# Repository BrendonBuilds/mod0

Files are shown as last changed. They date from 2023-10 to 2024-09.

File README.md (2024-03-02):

# mod0

### mod0 is an undefined, modular machine platform

- *This project is a work in progress*
- *Modules will be added as they are physically validated*
- *Expect files to change*

## Platform goals

- Extremely simple assembly that will result in precise control with minimal calibration
- Support for any combination of steppers (NEMA14/17), electronics (RRF/Klipper) and extruders
- Subcomponents can be assembled and calibrated independently
- Subcomponents can be separated for travel and quickly reassembled
- Packs flat for travel while staying mostly assembled
- Open Source

Feeling appreciative? Pay it forward! Consider supporting one of these charities!

[Sanjay Mortimer Foundation](https://www.sanjaymortimerfoundation.org/)

[Sanjay Mortimer Foundation PayPal](https://www.paypal.com/donate/?hosted_button_id=VUB6NVF83EH5J)

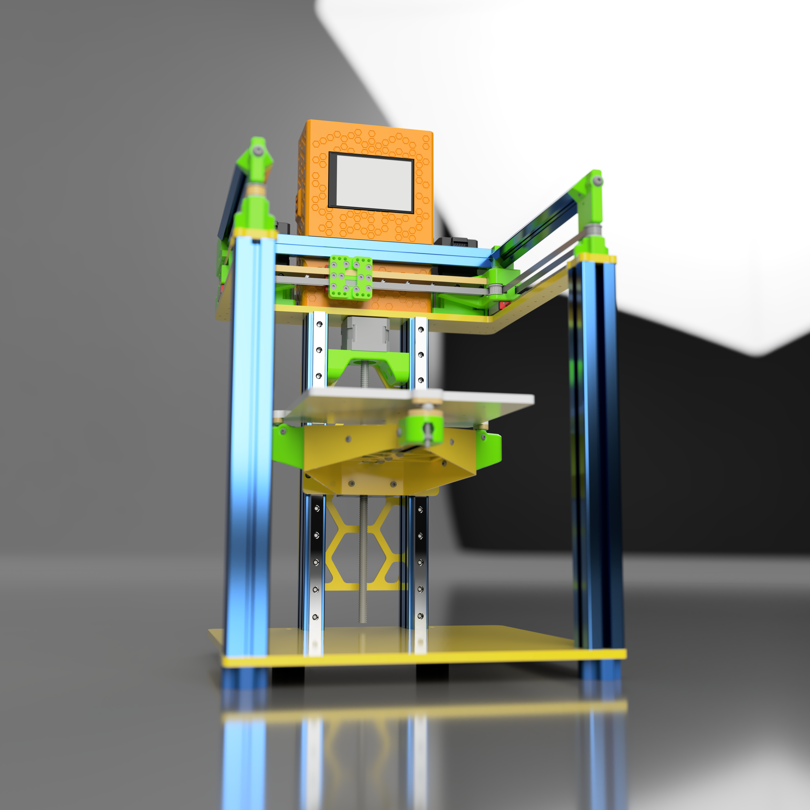
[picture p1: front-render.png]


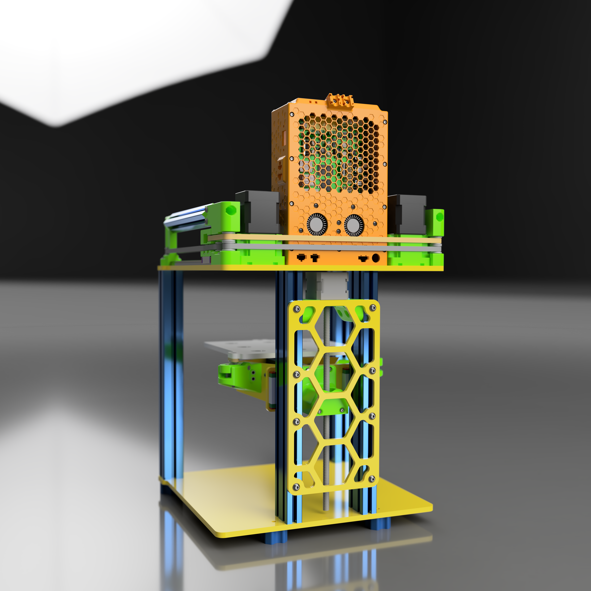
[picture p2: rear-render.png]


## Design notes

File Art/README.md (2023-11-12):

# mod0-Art

- *This project is a work in progress*
- *Expect files to change*
- *Template is subject to change if the shape of the base plate changes*

# Vista Print Car Door Decals

Vista Print offers a service which prints graphics for car door decals. This material adheres extremely well to polycarbonate/acrylic sheets and aluminum. They can be removed and reapplied if done carefully. The sticker is meant to be applied to the base of the machine.

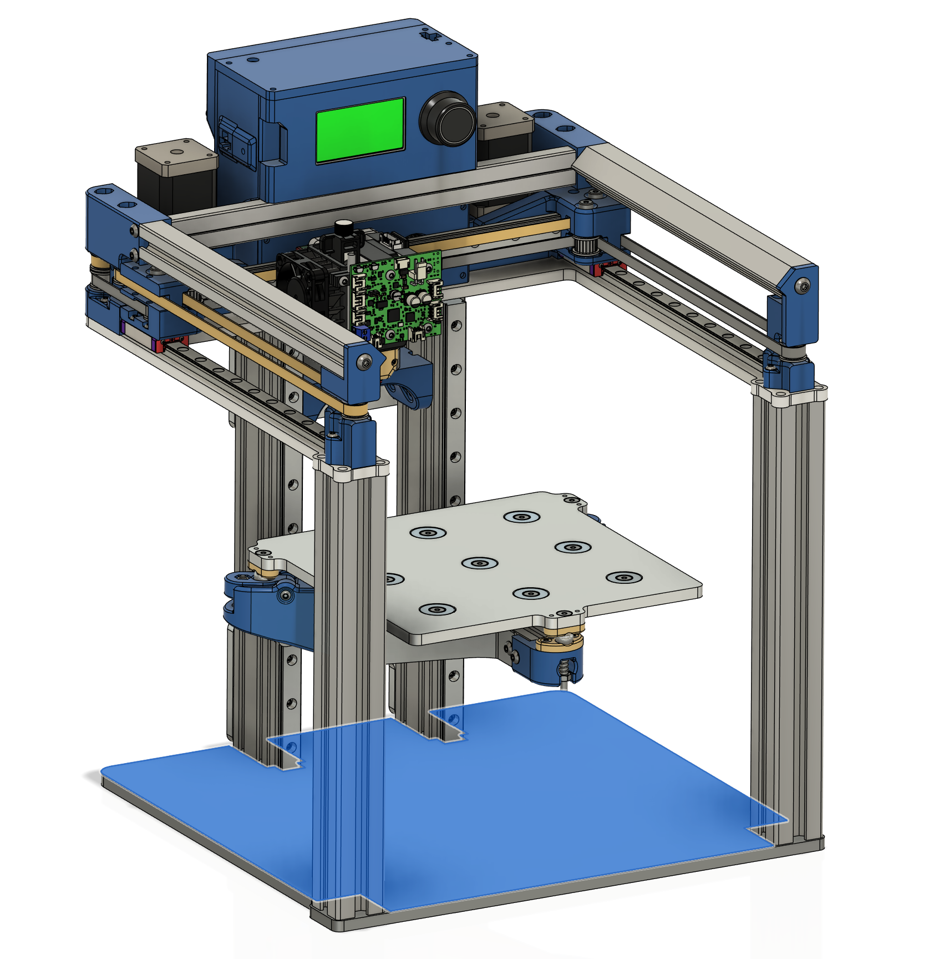
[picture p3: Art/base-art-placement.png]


The black area in *base-art-template* represents the area which will be used for the sticker. 

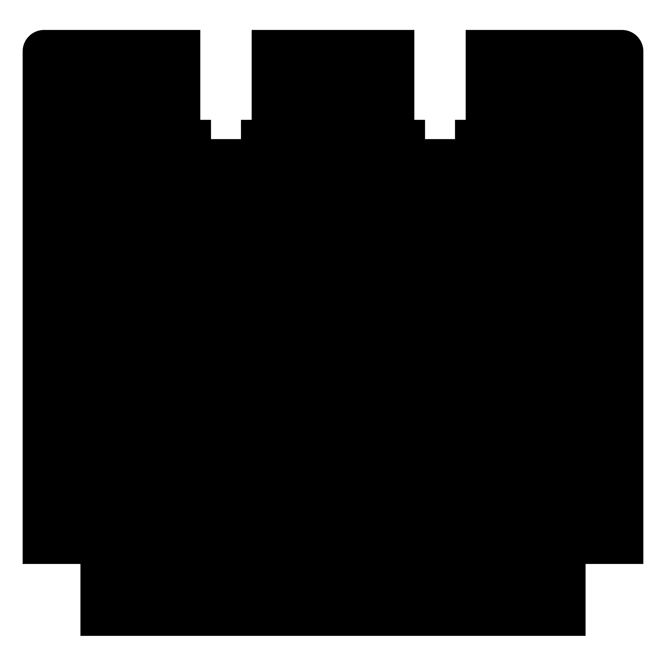
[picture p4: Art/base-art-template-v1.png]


This file is specifically sized for immediate upload to Vista Print for a 12-inch by 12-inch sticker (includes the safety and bleed areas). Note how the file appears when it has been uploaded.

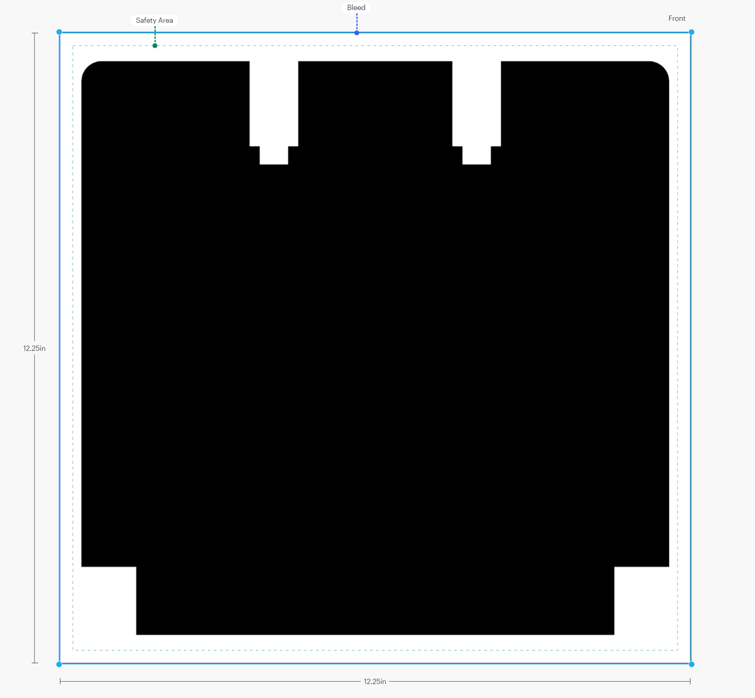
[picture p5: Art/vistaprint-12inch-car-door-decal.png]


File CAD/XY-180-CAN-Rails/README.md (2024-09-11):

# mod0-xy-180-CAN-Rails
- *This project is a work in progress*
- *Expect files to change*

This adaptation of mod0-xy-180 uses copper rods + target discs to transmit power and CAN signal lines to the extruder/gantry without the need for wiring. There are two copper rods positioned above each y-rail which interface with both ends of the x-rail via target discs using springs to maintain contact with the rods. There is then continuity from the ends of the x-rails to four copper rods which run the length of the x-axis. Four similarly configured target discs with springs on the gantry/extruder complete the circuit from the controller board through the rods on the x-axis.

It is 'somewhat easy' to replace the target discs; they will wear. Wear is greatly exacerbated when the target discs cannot be sprung consistently/smoothly in their mounting holes. The parts that retain the target discs were designed to be small and easy to remove such that they can be printed with a much finer layer height (100 micron recommended). Teardrop shapes have been placed in recesses to facilitate seam placement and help avoid unnecessary friction. It may require printing the parts many times in order to get adequate tolerances to ensure consistent communication and longevity of the target discs. The modular assembly + small part size should minimize waste during these iterations.

Uncoiling the springs and feeding them through the channels can be challenging, it will take practice. Carefully uncoil the spring and make a straight segment to simplify the process. Once the spring has exited the part, carefully pull on the loose end of the spring and it should uncoil into the recess. Leave approximately 6-8mm of spring outside of the recess for adequate compression against the target discs.

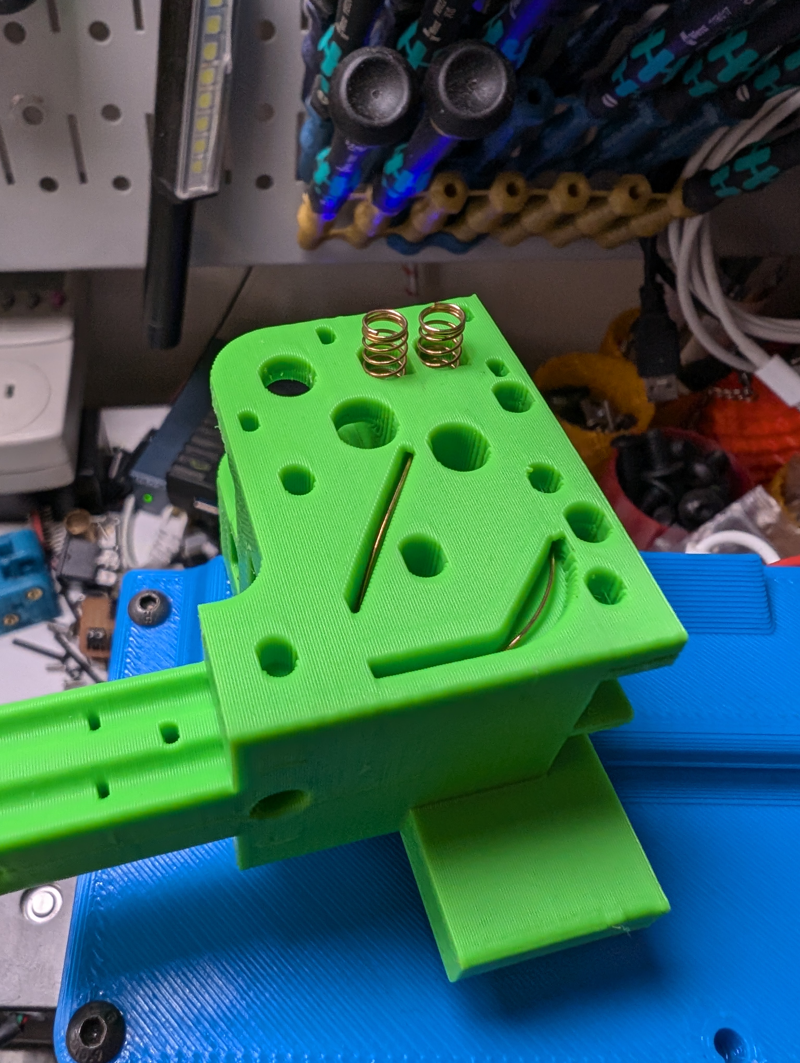
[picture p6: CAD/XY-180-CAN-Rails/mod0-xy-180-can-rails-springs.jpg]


## BOM

- Target Discs - https://www.digikey.com/en/products/detail/preci-dip/52051-1P0/22227123
- Copper (101) Rods - https://www.mcmaster.com/catalog/130/4328/8965K35
- Carbon Brushes for Springs - https://www.amazon.com/dp/B09C1HZW7V
- Flat Extrusion - https://us.misumi-ec.com/vona2/detail/110302374340
- Shoulder Bolts - 40mm (M3 thread) - https://us.misumi-ec.com/vona2/detail/110300249140/?HissuCode=MSB5-40
- Shoulder Bolts - 25mm (M4 thread) - https://www.filastruder.com/products/shoulder-screws-bolts?_pos=1&_sid=d9d5dbbc5&_ss=r&variant=16712544124999

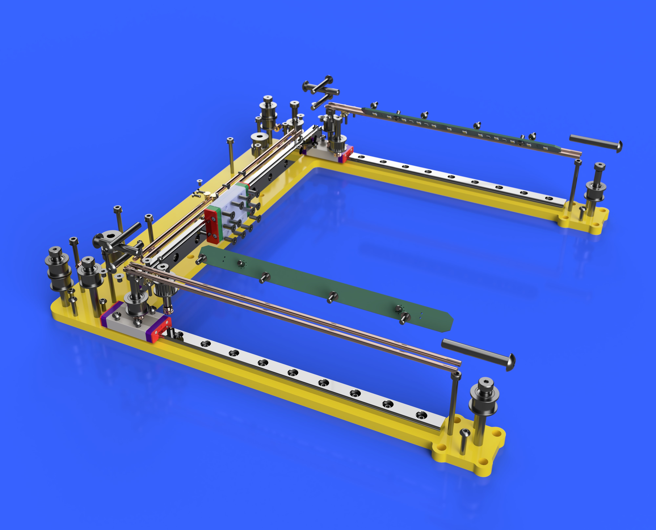
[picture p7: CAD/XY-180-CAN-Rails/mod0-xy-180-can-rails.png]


## MOVIES

### XY motion test
IMAGE ALT TEXT HERE (https://www.youtube.com/watch?v=eCRtHgMv8g4)

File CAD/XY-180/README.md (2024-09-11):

# mod0-xy-180

- *The folder has been renamed to XY-180, every variant in this folder has always had 180x180mm of travel*
- *v1 & v2 files will not be renamed '-180' despite sharing an identical x/y plate with every variant in this folder*
- *This project is a work in progress*
- *Expect files to change*

# mod0-xy-180-v3

## BOM

- Flat Extrusion - https://us.misumi-ec.com/vona2/detail/110302374340
- Shoulder Bolts - 40mm (M3 thread) - https://us.misumi-ec.com/vona2/detail/110300249140/?HissuCode=MSB5-40
- Shoulder Bolts - 25mm (M4 thread) - https://www.filastruder.com/products/shoulder-screws-bolts?_pos=1&_sid=d9d5dbbc5&_ss=r&variant=16712544124999

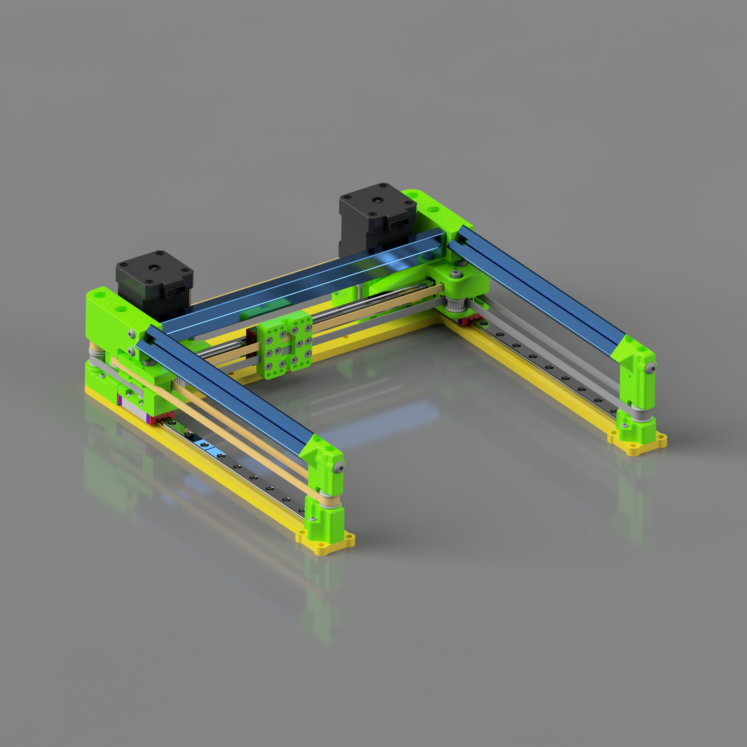
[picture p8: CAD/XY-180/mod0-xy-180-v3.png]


# mod0-xy-175-v2 (identical to v1 with some cleanup)

## BOM

- 45 Degree Angled Extrusion - https://us.misumi-ec.com/vona2/detail/110302685230/
- Flat Extrusion - https://us.misumi-ec.com/vona2/detail/110302374340
- Shoulder Bolts - 40mm (M3 thread) - https://us.misumi-ec.com/vona2/detail/110300249140/?HissuCode=MSB5-40
- Shoulder Bolts - 25mm (M4 thread) - https://www.filastruder.com/products/shoulder-screws-bolts?_pos=1&_sid=d9d5dbbc5&_ss=r&variant=16712544124999

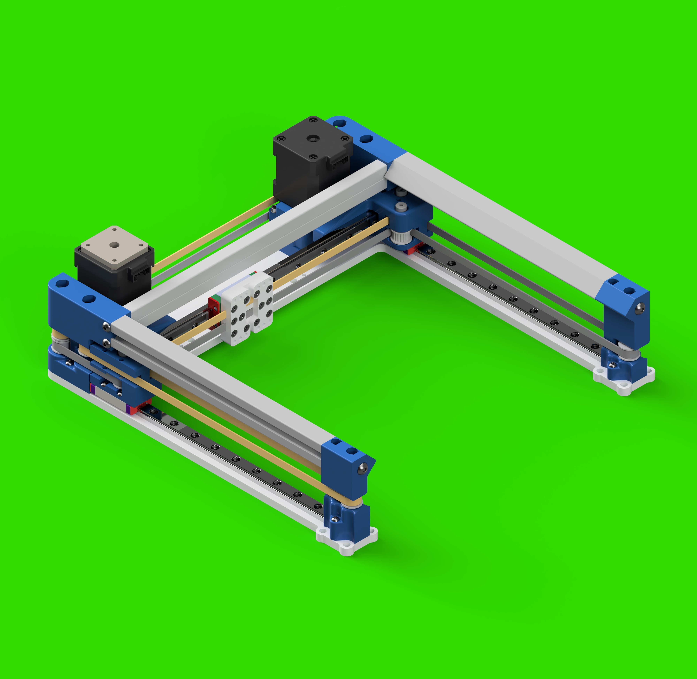
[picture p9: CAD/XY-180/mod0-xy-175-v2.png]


# mod0-xy-175-v1 (deprecated)

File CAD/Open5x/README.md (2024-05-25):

# mod0-open5x-v1

- *This project is a work in progress*
- *Expect files to change*

## BOM

- FLY RRF 36 Toolboards
  - https://teamgloomy.github.io/fly_rrf_36_general.html
- 10mm Shaft Clamp
  - https://www.amazon.com/gp/product/B07QS7MX85
- 10mm Shaft Collar
  - https://www.amazon.com/gp/product/B0C9QTP89C
- IGUS slewing ring
  - https://www.igus.com/product?artNr=PRT-02-20-LC

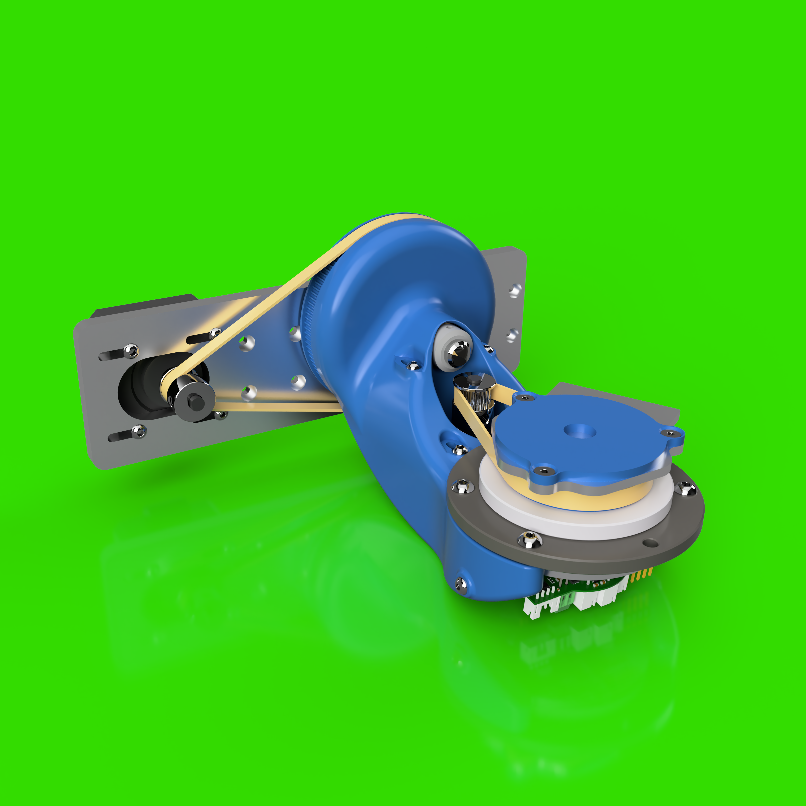
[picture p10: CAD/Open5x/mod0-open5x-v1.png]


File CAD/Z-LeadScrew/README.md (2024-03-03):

# mod0-z-leadscrew-300-v2

- *This project is a work in progress*
- *Expect files to change*
- *Approximately 210mm of build-height with the Hemera XS extruder*

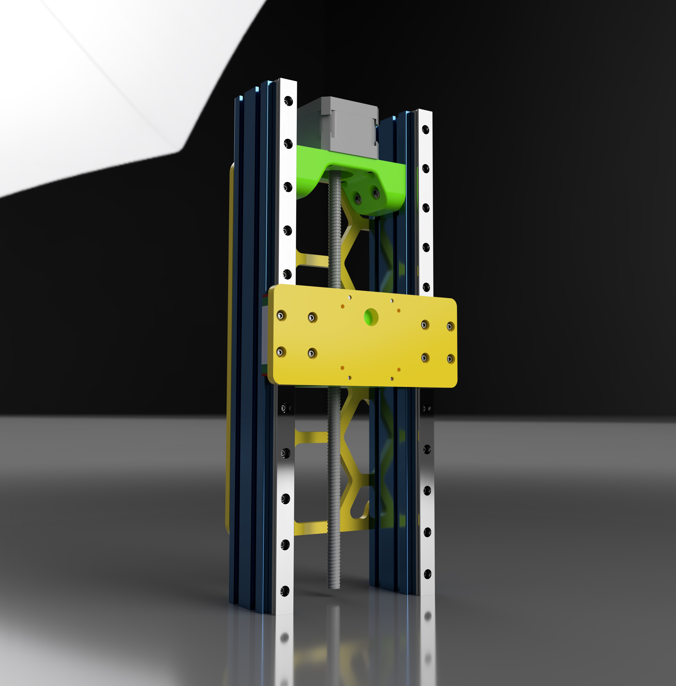
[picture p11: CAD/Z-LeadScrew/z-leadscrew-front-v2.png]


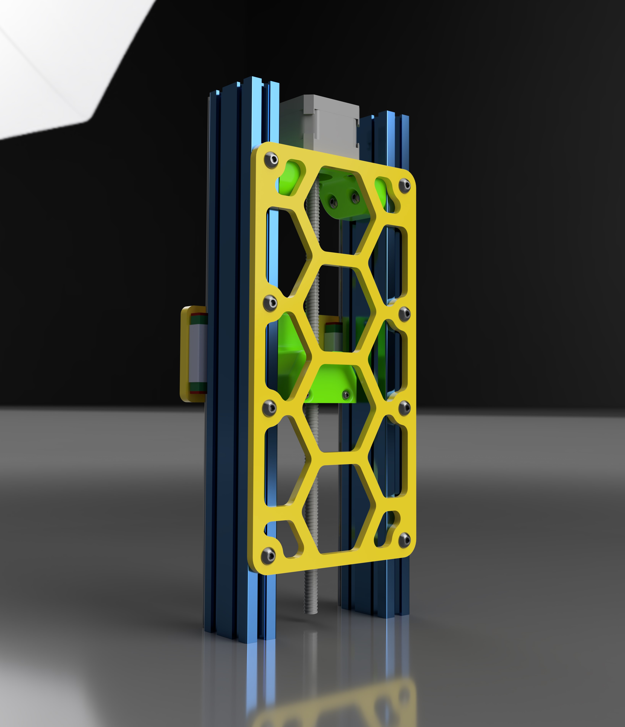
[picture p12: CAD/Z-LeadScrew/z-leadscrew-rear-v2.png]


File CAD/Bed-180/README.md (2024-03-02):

# mod0-bed-180-v1

- *This project is a work in progress*
- *Expect files to change*
- *A drag chain will be added in the near future*

## Available Parts

Thanks to the generous support from Mandala Rose Works the bed is available for purchase:

https://mandalaroseworks.com/collections/brendon-builds-mod0 

## BOM

- 10mm Beads - https://www.amazon.com/dp/B0BB29FDZJ
- Magnets - https://mandalaroseworks.com/products/chamfered-magnet-150c
- Springs - https://www.amazon.com/dp/B008RFGNGA

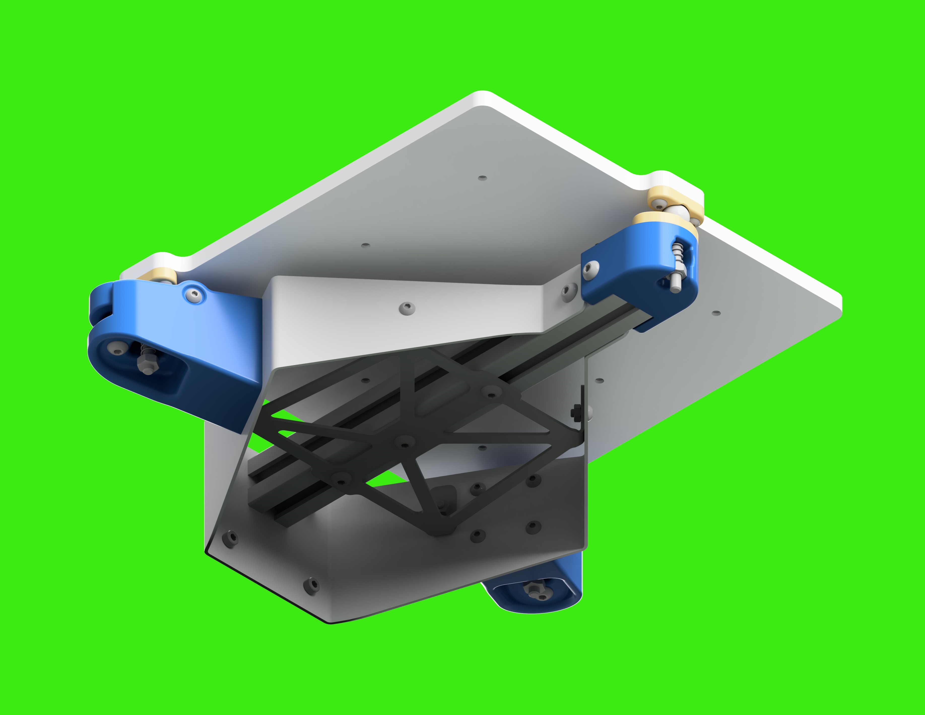
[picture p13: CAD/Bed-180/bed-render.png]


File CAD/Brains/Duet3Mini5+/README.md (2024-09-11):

# mod0-brains-duet3mini5
- *This project is a work in progress*
- *Expect files to change*

# mod0-brains-duet3mini5-extraCAN-v1
- Identical to mod0-brains-duet3mini5-v1 except:
  - Added 1x 4p nanofit connector to both side panels
  - Added 3x 4p nanofit connectors to the rear panel
  - Adjusted top/external wire routing to match Klipper brain

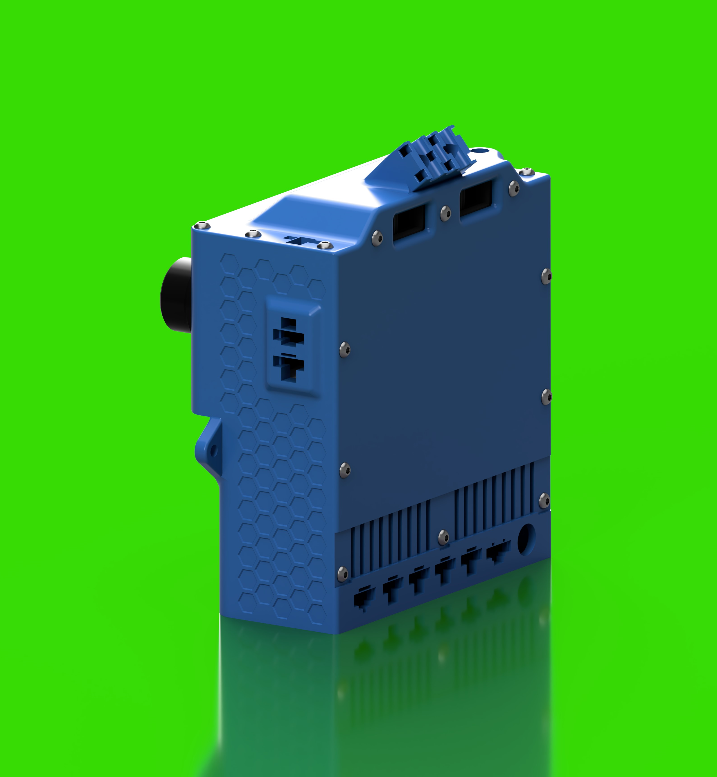
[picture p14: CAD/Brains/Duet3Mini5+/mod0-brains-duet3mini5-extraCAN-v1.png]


# mod0-brains-duet3mini5-v1

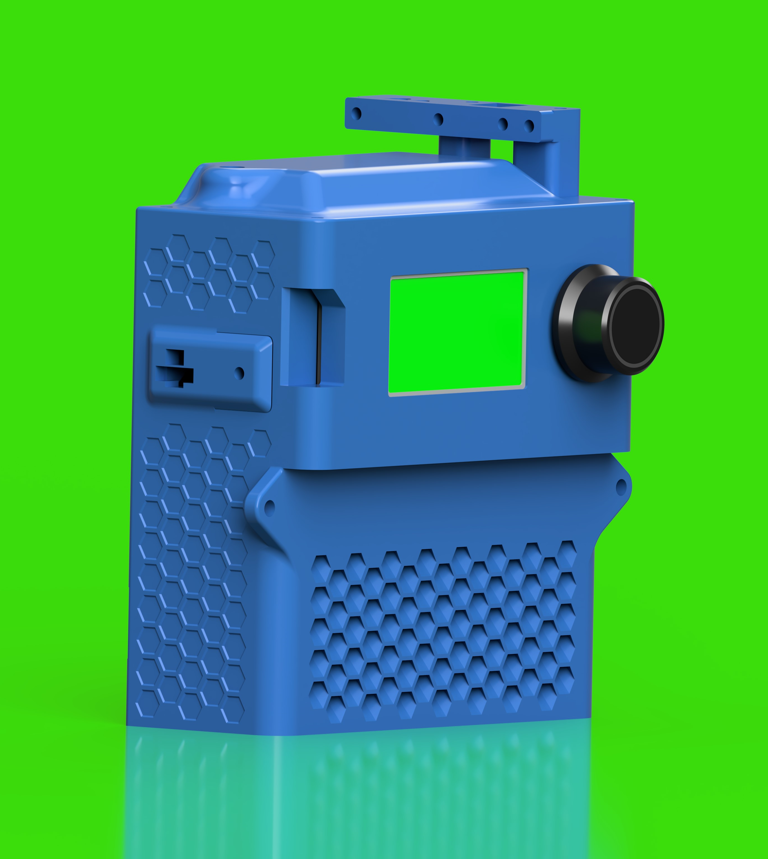
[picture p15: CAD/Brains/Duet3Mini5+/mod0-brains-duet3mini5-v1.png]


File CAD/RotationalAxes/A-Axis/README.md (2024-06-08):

# mod0-a-axis-v1

- *This project is a work in progress*
- *Expect files to change*

## BOM

- Open5x adapter plate
  - https://mandalaroseworks.com/products/mod0-open5x-adapter-plate
- 80T 2GT Pulleys
  - https://www.amazon.com/gp/product/B0BK566MR8
- C16 Collet Chuck
  - https://www.amazon.com/gp/product/B07YDGKKP5
- C10 Collet Chuck
  - https://www.amazon.com/gp/product/B082HWYT5V

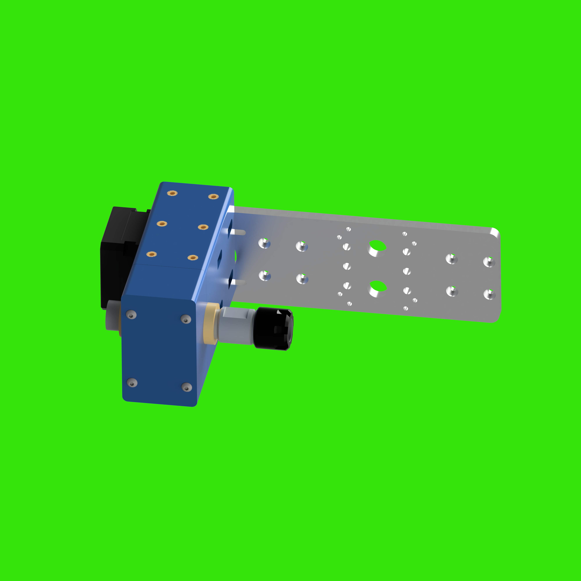
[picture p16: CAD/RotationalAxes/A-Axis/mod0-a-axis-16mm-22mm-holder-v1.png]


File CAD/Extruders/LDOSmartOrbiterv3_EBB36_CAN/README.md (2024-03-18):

# LDOSmartOrbiterv3_EBB36_CAN_magZ-v1

- *This project is a work in progress*
- *Expect files to change*

## BOM

- Magnetic Connectors - https://www.adafruit.com/product/5360
- Limit Switch - https://www.digikey.com/en/products/detail/omron-electronics-inc-emc-div/D2GW-A02D/15963578
- Micro-Fit Cable - https://www.digikey.com/en/products/detail/molex/2451320420/6565375

## Reference Models

- EBB 36 Toolboards
  - https://github.com/bigtreetech/EBB
- LDO Smart Orbiter v3:
  - https://www.orbiterprojects.com/so3/

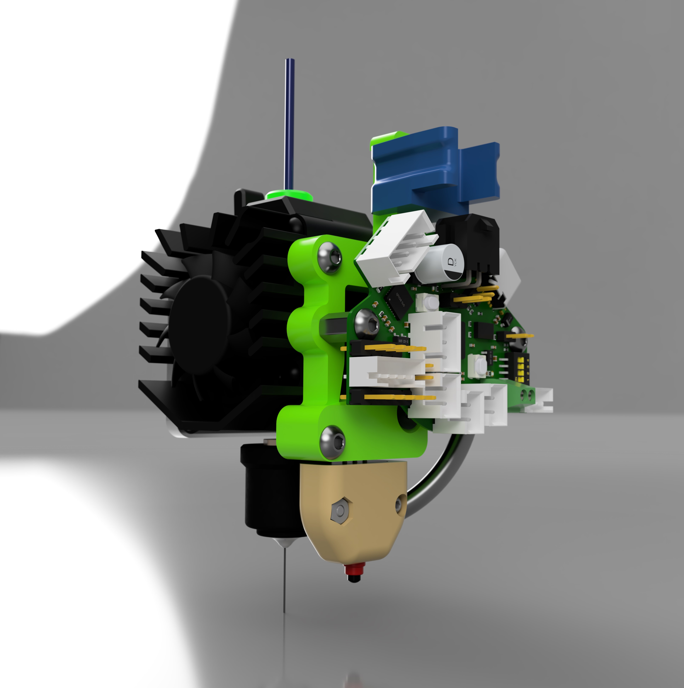
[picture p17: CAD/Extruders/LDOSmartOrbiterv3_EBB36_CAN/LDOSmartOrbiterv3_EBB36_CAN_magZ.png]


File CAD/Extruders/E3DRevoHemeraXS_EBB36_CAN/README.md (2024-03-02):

# E3DRevoHemeraXS_EBB36_CAN_magZ-v1

- *This project is a work in progress*
- *Expect files to change*

## BOM

- Magnetic Connectors - https://www.adafruit.com/product/5360
- Limit Switch - https://www.digikey.com/en/products/detail/omron-electronics-inc-emc-div/D2GW-A02D/15963578
- Micro-Fit Cable - https://www.digikey.com/en/products/detail/molex/2451320420/6565375

## Reference Models

- EBB 36 Toolboards
  - https://github.com/bigtreetech/EBB
- E3D Hemera XS:
  - https://e3d-online.com/products/revo-hemera-xs
  - https://cdn.shopify.com/s/files/1/0259/1948/8059/files/Hemera_XS_Reference_CAD.STEP?v=1693395523

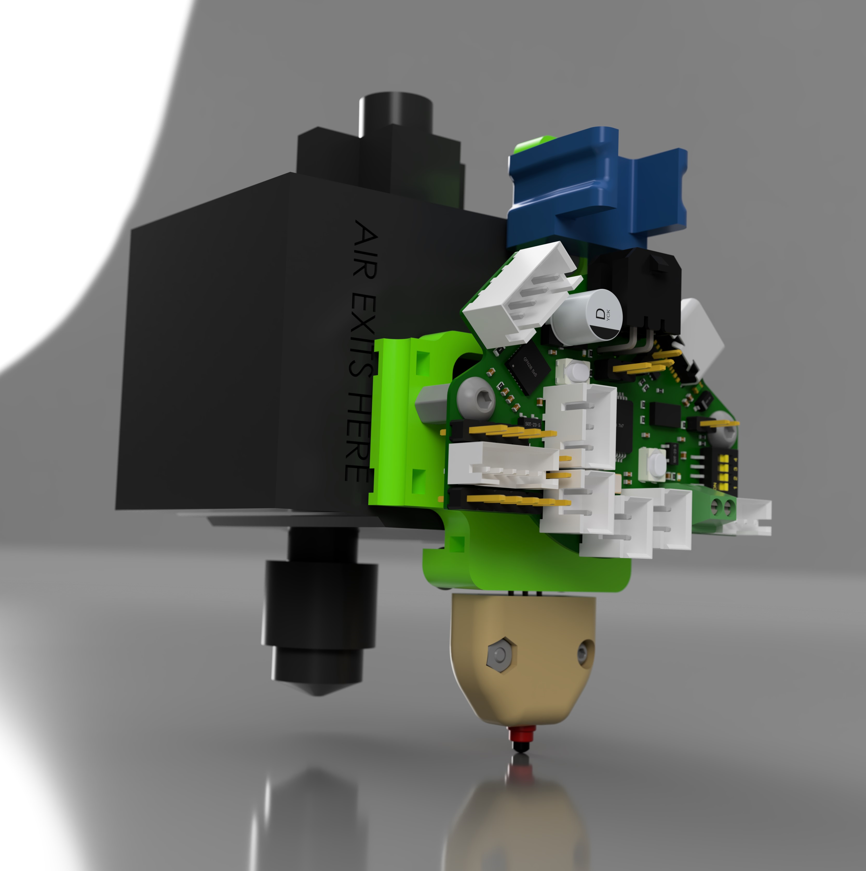
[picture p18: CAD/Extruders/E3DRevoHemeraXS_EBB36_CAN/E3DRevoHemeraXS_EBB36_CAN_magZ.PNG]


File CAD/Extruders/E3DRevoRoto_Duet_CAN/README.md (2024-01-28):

# E3DRevoRoto_DuetCAN_magZ-v1

- *This project is a work in progress*
- *Expect files to change*

## BOM

- Magnetic Connectors - https://www.adafruit.com/product/5360
- Limit Switch - https://www.digikey.com/en/products/detail/omron-electronics-inc-emc-div/D2GW-A02D/15963578

## Reference Models

- Duet Roto Toolboard
  - https://www.duet3d.com/Duet3RotoToolboard
  - https://github.com/Duet3D/Duet3-RotoToolboard
- E3D Roto:
  - https://e3d-online.com/products/roto-extruder
  - https://www.printables.com/model/655950-e3d-roto-reference-cad

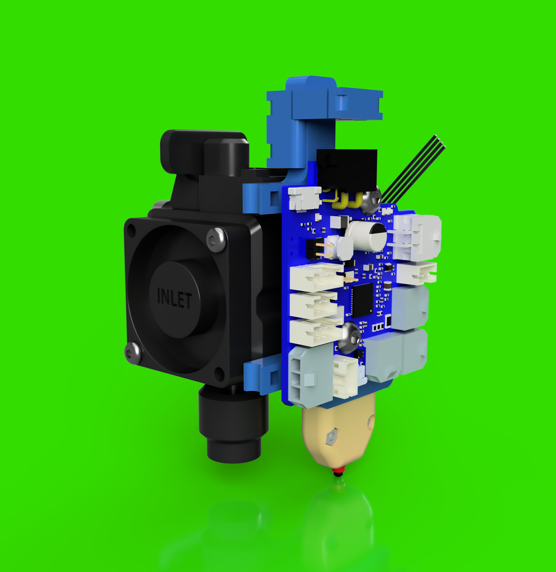
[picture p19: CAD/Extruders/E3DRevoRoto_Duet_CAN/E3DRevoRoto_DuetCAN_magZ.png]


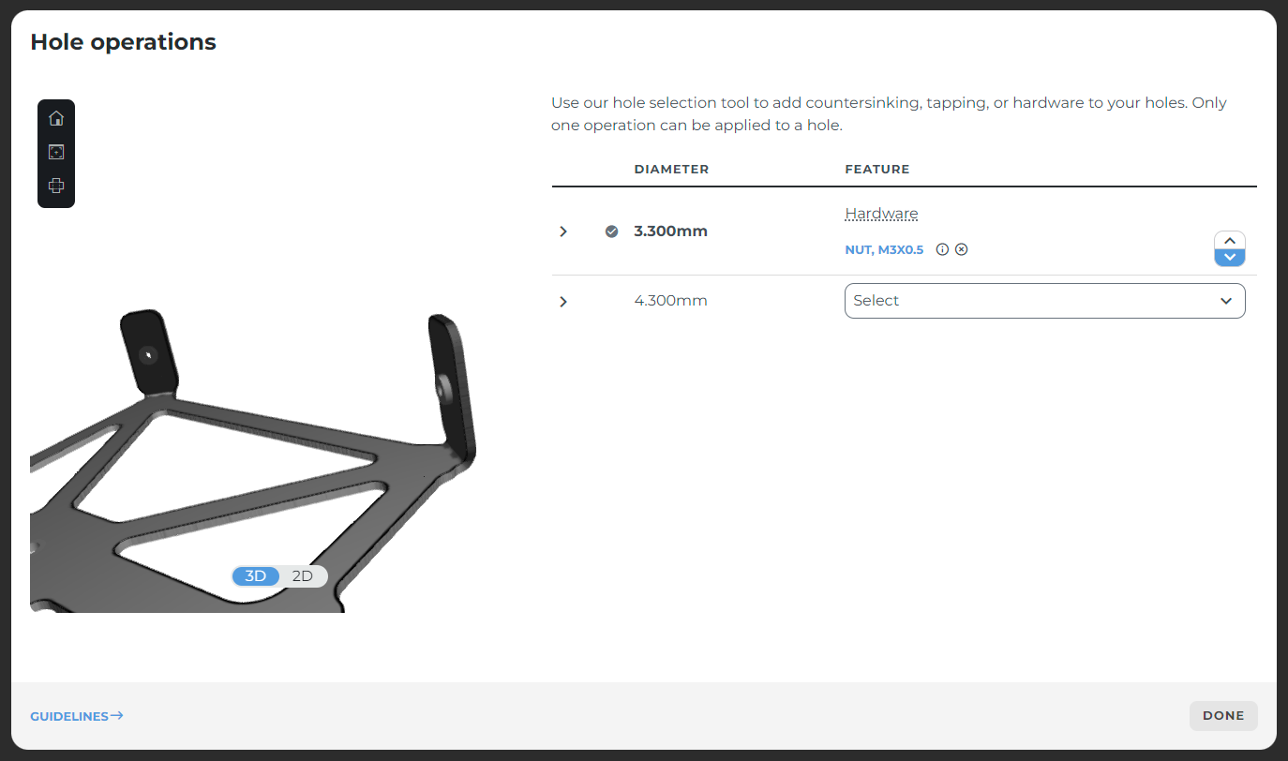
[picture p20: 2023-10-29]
CAD/Bed-180/bed-support-hardware-g30-galvanized-0.048in-v1.png

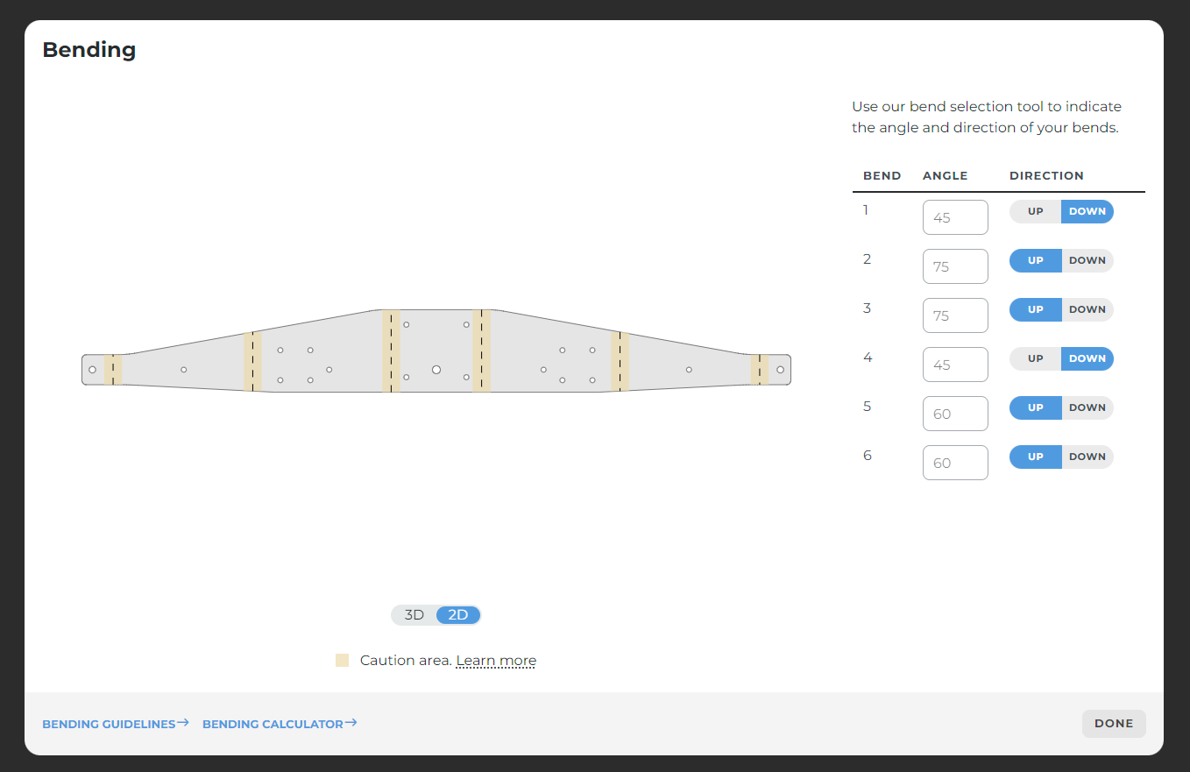
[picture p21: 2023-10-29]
CAD/Bed-180/bed-base-bends-stainless-steel-0.048in-v1.png

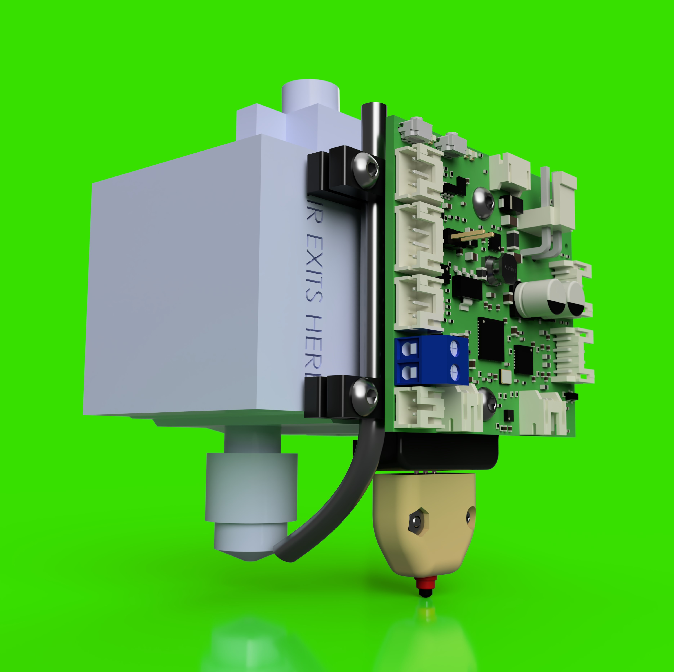
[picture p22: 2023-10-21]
CAD/Extruders/E3DRevoHemeraXS_Duet_CAN/E3DRevoHemeraXS_DuetCAN_magZ.png

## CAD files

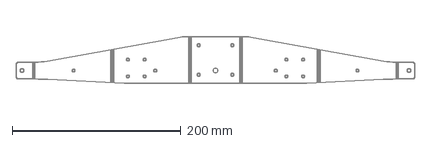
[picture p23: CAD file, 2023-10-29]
CAD/Bed-180/mod0-bed-base-stainless-steel-0.048in-v1.dxf
472.3 x 55.0 mm

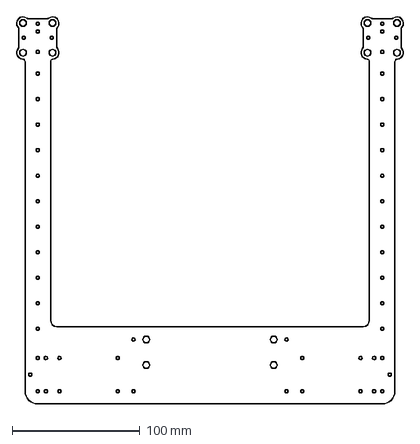
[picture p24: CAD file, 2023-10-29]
CAD/XY-180/mod0-xy-plate-v1.dxf
304.2 x 304.1 mm

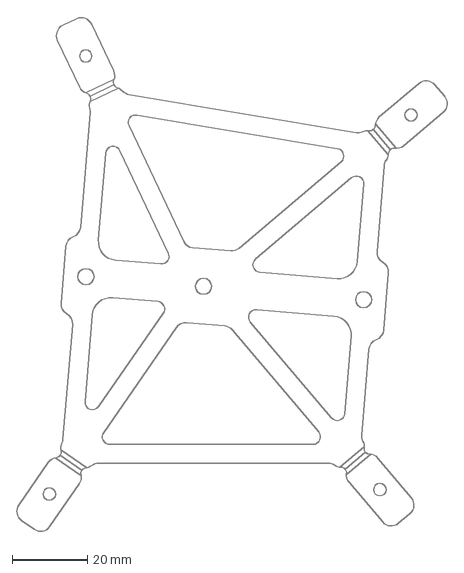
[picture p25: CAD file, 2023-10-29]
CAD/Bed-180/mod0-bed-support-g30-galvanized-0.048in-v1.dxf
114.4 x 137.2 mm

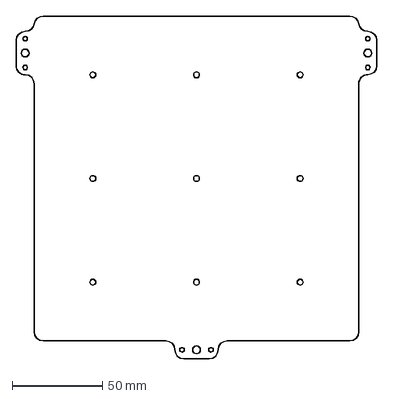
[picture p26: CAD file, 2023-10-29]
CAD/Bed-180/mod0-bed-no-pockets-180mm-6061-0.25in-v1.dxf
200.0 x 190.0 mm

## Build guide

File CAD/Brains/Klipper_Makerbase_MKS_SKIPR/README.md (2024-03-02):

# mod0-brains-mks-skipr-v1

- *This project is a work in progress*
- *Expect files to change*

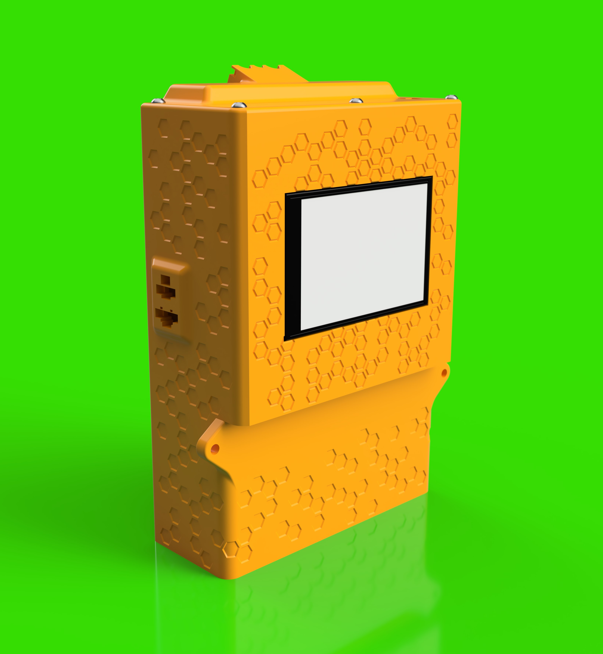
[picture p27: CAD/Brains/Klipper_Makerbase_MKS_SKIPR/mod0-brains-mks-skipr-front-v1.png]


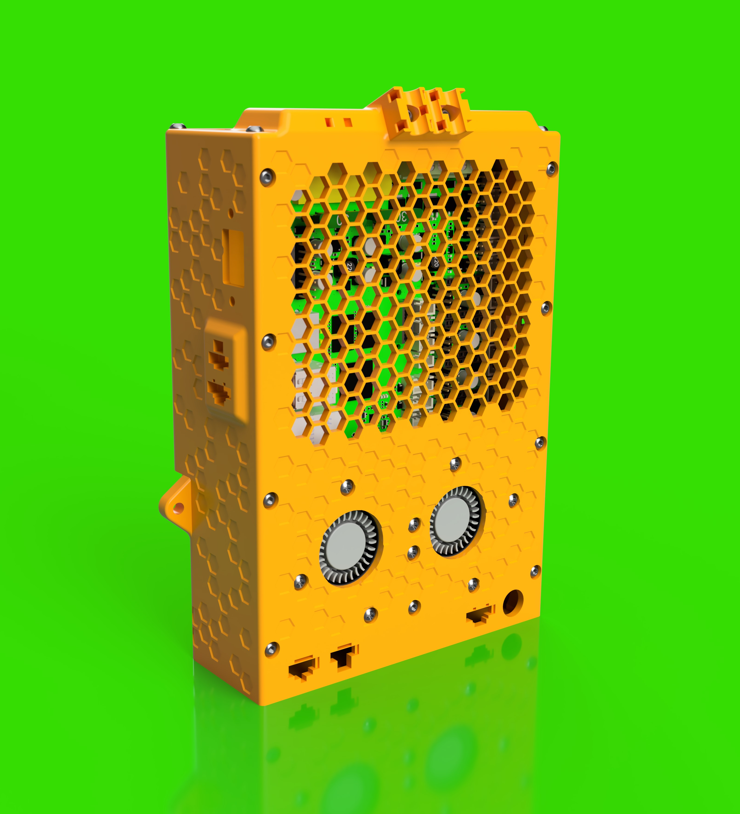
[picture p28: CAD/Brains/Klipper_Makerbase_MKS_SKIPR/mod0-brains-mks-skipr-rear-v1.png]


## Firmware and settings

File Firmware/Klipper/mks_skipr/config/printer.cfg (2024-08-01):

[include moonraker_obico_macros.cfg]
[include mainsail.cfg]
[include fluidd.cfg]
# This file contains common pin mappings for MKS SKIPR
# boards. To use this config, the firmware should be compiled for the
# stm32f407. When running "make menuconfig", select the 48KiB
# bootloader, and enable "Serial for communication" and select the "on USART1 PA10/PA9"

# The "make flash" command does not work on the MKS SKIPR. Instead,
# after running "make", copy the generated "out/klipper.bin" file to a
# file named "mks_skipr.bin" on an SD card and then restart the
# MKS SKIPR with that SD card.

# See docs/Config_Reference.md for a description of parameters.
[mcu]
# The hardware use USART1 PA10/PA9 connect to RK3328
# serial: /dev/ttyS0
canbus_interface: can0
canbus_uuid: dfa851643837 # replace with the appopriate CAN address

[mcu EBBCan]
canbus_interface: can0
canbus_uuid: 8596ed209d34

[stepper_x]
step_pin: PE1
dir_pin: !PE0
enable_pin: !PE2
microsteps: 4
rotation_distance: 40
full_steps_per_rotation: 400
endstop_pin: !PA14
position_min: 0  
position_endstop: 160
position_max: 160
homing_speed:50
homing_retract_dist: 5
homing_positive_dir: true
step_pulse_duration: 0.000008

[stepper_y]
step_pin: PB5
dir_pin: !PB4
enable_pin: !PB6
microsteps: 4
rotation_distance: 40
full_steps_per_rotation: 400
endstop_pin: !PA15
position_min: 0
position_endstop: 180
position_max: 180
homing_speed: 50
homing_retract_dist: 5
homing_positive_dir: true
step_pulse_duration: 0.000008

[stepper_z]
step_pin: PD6
dir_pin: PD5
enable_pin: !PD7
microsteps: 16
rotation_distance: 2
full_steps_per_rotation: 200
endstop_pin:probe:z_virtual_endstop
position_max: 215
position_min: -5 
homing_speed: 8
second_homing_speed: 3

[extruder]
step_pin: EBBCan: PD0
dir_pin: EBBCan: PD1
enable_pin: !EBBCan: PD2
microsteps: 16
rotation_distance: 8.19 # Hemera XS
# rotation_distance: 4.57 # orbiter v3
nozzle_diameter: 0.400
filament_diameter: 1.750
min_temp: 0
min_extrude_temp: 0
max_temp: 350
heater_pin: EBBCan:PB13
sensor_type: PT1000 # e3d high temp heater block
#sensor_type: ATC Semitec 104NT-4-R025H42G # orbiter v3 hotend
sensor_pin: EBBCan:PA3
max_power: 1.0
control : pid  
#pid_kp : 22.146 # orbiter v3 hotend, 275c
#pid_ki : 1.659 # orbiter v3 hotend, 275c
#pid_kd : 73.912 # orbiter v3 hotend, 275c
pid_kp : 20.865 # e3d high temp heater block, 275c
pid_ki : 1.179 # e3d high temp heater block, 275c
pid_kd : 92.327 # e3d high temp heater block, 275c
pressure_advance: 0.019
pressure_advance_smooth_time: 0.01
max_extrude_cross_section: 20
instantaneous_corner_velocity: 1.000
max_extrude_only_distance: 500.0
max_extrude_only_velocity: 5000
max_extrude_only_accel: 5000
step_pulse_duration: 0.000004

[heater_bed]
heater_pin: PD12
sensor_type: NTC 100K MGB18-104F39050L32
sensor_pin: PC0
max_power: 1.0
control = pid
pid_kp = 55.590
pid_ki = 1.930
pid_kd = 400.248
min_temp: 0
max_temp: 150
pwm_cycle_time: 0.01666 # removes LED flicker, likely 0.02 for 50hz power

#fan for printed model FAN0
[fan]
pin: PA2
cycle_time: 0.03333333333

#fan for hotend FAN1
[heater_fan fan1]
pin: EBBCan: PA1
heater_temp: 80
shutdown_speed: 1

#fan for board cooling
[heater_fan fan2]
pin: PA0
heater_temp: 10
shutdown_speed: 1

#fan for board cooling
[heater_fan fan3]
pin: PA1
heater_temp: 10
shutdown_speed: 1

[led left_led]
white_pin: PB0
initial_white: 1.0

[led left_right]
white_pin: PB1
initial_white: 1.0

####################################################################
#	Homing and Gantry Adjustment Routines
#####################################################################
[force_move]
enable_force_move: True

[idle_timeout]
timeout: 3600

[bed_mesh]
speed: 500
horizontal_move_z: 10
mesh_min: 28, 23
mesh_max: 150, 149
probe_count: 3, 3

#####################################################################
# 	Probe
#####################################################################
[probe]
pin: EBBCan: PB7
# x_offset: 13
x_offset: 13
y_offset: -29.0
z_offset: 3.92 # adding positive value decreases distance to bed
speed: 10.0
samples: 1
samples_result: median
sample_retract_dist: 3.0
samples_tolerance: 0.05
samples_tolerance_retries: 1

[printer]
kinematics:corexy
max_velocity: 1700
max_accel: 6500
max_accel_to_decel: 6500
max_z_velocity: 20
max_z_accel: 400
square_corner_velocity: 6.0

########################################
# TMC UART configuration
########################################
[tmc2209 stepper_x]
uart_pin: PB3
run_current: 1.6
hold_current: 0.5
interpolate: True
stealthchop_threshold: 0

[tmc2209 stepper_y]
uart_pin: PB7
run_current: 1.6
hold_current: 0.5
interpolate: True
stealthchop_threshold: 0

[tmc2209 stepper_z]
uart_pin: PD4
run_current: 1.1
hold_current: 0.5
interpolate: True
stealthchop_threshold: 0

[tmc2209 extruder]
uart_pin: EBBCan: PA15
run_current: 1.0
hold_current: 0.5
interpolate: True
stealthchop_threshold: 400

########################################
# EXP1 / EXP2 (display) pins
########################################
[board_pins]
aliases:
    # EXP1 header
    EXP1_1=PB2,  EXP1_3=PE11, EXP1_5=PD9, EXP1_7=PE15, EXP1_9=<GND>,
    EXP1_2=PE10, EXP1_4=PD10, EXP1_6=PD8, EXP1_8=PE7,  EXP1_10=<5V>,
    # EXP2 header
    EXP2_1=PA6, EXP2_3=PE9, EXP2_5=PE8, EXP2_7=PD13,  EXP2_9=<GND>,
    EXP2_2=PA5, EXP2_4=PA4, EXP2_6=PA7, EXP2_8=<RST>, EXP2_10=<3.3v>
    # Pins EXP2_1, EXP2_6, EXP2_2 are also MISO, MOSI, SCK of bus "ssp1"

    # See the sample-lcd.cfg file for definitions of common LCD displays.

# Some alternate glyphs for use with 128x64 LCDs. These are used by
# adding them to your printer.cfg.

# See docs/Config_Reference.md for a description of parameters.

######################################################################
# MKS Mini 12864v3.0 (with neopixel backlight leds)
######################################################################
[display]
lcd_type: uc1701
cs_pin: EXP1_3
a0_pin: EXP1_4
rst_pin: EXP1_5
contrast: 63
encoder_pins: ^EXP2_5, ^EXP2_3
click_pin: ^!EXP1_2
## Some micro-controller boards may require an spi bus to be specified:
#spi_bus: spi
## Alternatively, some micro-controller boards may work with software spi:
spi_software_miso_pin: EXP2_1
spi_software_mosi_pin: EXP2_6
spi_software_sclk_pin: EXP2_2

[output_pin beeper]
pin: EXP1_1

[neopixel fysetc_mini12864]
pin: EXP1_6
chain_count: 3
color_order: RGB
initial_RED: 1.0
initial_GREEN: 1.0
initial_BLUE: 0.0

# See the MKS Lcd Config path file for definitions of common LCD displays.

[mcu rpi]
serial: /tmp/klipper_host_mcu

[adxl345]
cs_pin: rpi:None
spi_bus: spidev0.2

[resonance_tester]
accel_chip: adxl345
probe_points:
    100, 100, 20  # an example

[input_shaper]
shaper_freq_x: 60.0
shaper_type_x: mzv
shaper_freq_y: 55.0
shaper_type_y: mzv

[virtual_sdcard]
#path:/home/mks/uploads
path: ~/printer_data/gcodes

[pause_resume]

[gcode_macro CANCEL_PRINT]
description: Cancel the actual running print
rename_existing: CANCEL_PRINT_BASE
gcode:
  TURN_OFF_HEATERS
  CANCEL_PRINT_BASE

[display_status]

[gcode_macro HOME_ALL]
gcode:
    SET_KINEMATIC_POSITION X=155 Y=0 Z=20
    G91
    SET_TMC_CURRENT STEPPER=stepper_x CURRENT=1.6 HOLDCURRENT=0.5
    SET_TMC_CURRENT STEPPER=stepper_y CURRENT=1.6 HOLDCURRENT=0.5
    G1 X5 F600
    G90
    SET_TMC_CURRENT STEPPER=stepper_x CURRENT=0.35 HOLDCURRENT=0.3
    SET_TMC_CURRENT STEPPER=stepper_y CURRENT=0.35 HOLDCURRENT=0.3
    G1 y178 f9000
    G1 x2 f9000
    G1 x0 y180 f9000
    SET_KINEMATIC_POSITION X=0 Y=180 Z=20
    G1 x15 y52
    G28 z
    G1 z10
    SET_TMC_CURRENT STEPPER=stepper_x CURRENT=1.6 HOLDCURRENT=0.5
    SET_TMC_CURRENT STEPPER=stepper_y CURRENT=1.6 HOLDCURRENT=0.5

[gcode_macro G29]
gcode:
    BED_MESH_CALIBRATE
    G1 X0 Y180

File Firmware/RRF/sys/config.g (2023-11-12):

; Configuration file for Duet 3 Mini 5+ (firmware version 3.4.6)
; executed by the firmware on start-up
;

; General preferences
G90							; send absolute coordinates...
M83							; ...but relative extruder moves
M550 P"mod0"				; set printer name
M669 K1						; select CoreXY mode
M552 S1						; enable wifi

; use out2 for CAN/extruder power
M950 F9 C"out2"
M106 P9 S1
G4 S2						; slight delay for power to enable CAN device

; Network
M586 P0 S1					; enable HTTP
M586 P1 S1					; enable FTP
M586 P2 S0					; disable Telnet

; Drives
M569 P0.0 S0					; physical drive 0.0 goes backwards
M569 P0.2 S1					; physical drive 0.2 goes forwards
M569 P0.3 S0					; physical drive 0.3 goes backwards
M569 P25.0 S0					; physical drive 25.0 goes backwards

M584 X0.0 Y0.3 Z0.2 E25.0					; set drive mapping
M350 X16 Y16 Z16 E16 I1						; configure microstepping with interpolation
M92 X152.38095238 Y152.38095238 Z1600 E398	; set steps per mm
M566 X1100 Y1100 Z200 E300					; set maximum instantaneous speed changes (mm/min)
M203 X60000 Y60000 Z1800 E5000				; set maximum speeds (mm/min)
M201 X6500 Y6500 Z400 E5000					; set accelerations (mm/s^2)
M906 X1680 Y1680 Z1330 E1000 I30			; set motor currents (mA) and motor idle factor in per cent
M84 S30										; Set idle timeout

; Axis Limits
M208 X0 Y0 Z0 S1			; set axis minima
M208 X160 Y180 Z200 S0		; set axis maxima

; Endstops
M574 X2 S3					; configure sensorless homing for high end of x
M574 Y2 S3					; configure sensorless homing for high end of Y
M574 Z1 S2					; configure Z-probe endstop for low end on Z

; Z-Probe
M558 P8 C"^25.io2.in" H2.5 F360 T40000 R1	; Set Z probe type to NC switch and the dive height + speeds
G31 P500 X13 Y-29 Z4.03						; set Z probe trigger value, offset and trigger height, -z separates from bed, +z brings nozzle tip closer
M557 X14:165 Y13:147 P2						; define mesh grid

; Bed Heater
M308 S0 P"temp2" Y"thermistor" T100000 B3950		; configure sensor 0 as thermistor on pin temp0
M950 H0 C"out0" T0									; create bed heater output on out0 and map it to sensor 0
M307 H0 R0.604 K0.361:0.000 D5.92 E1.35 S1.00 B0	; 180mm bed, 170mm pad, 180w, 24v DC bed, 80c (fysetc)
M140 H0												; map heated bed to heater 0
M143 H0 S100										; set temperature limit for heater 0 to 150C

; Nozzle Heater
M308 S1 P"25.temp0" Y"pt1000"							; configure sensor 1 as pt1000 on pin temp0
M950 H1 C"25.out0" T1									; create nozzle heater output on out0 and map it to sensor 1
M307 H1 R3.362 K0.248:0.115 D6.24 E1.35 S1.00 B0 V24.1	; revo HT, 65w heater, 285c, 20w air pump
M143 H1 S400											; limit nozzle to 400c

; Part Cooling
M950 F0 C"out4" Q30				; create fan 0 on pin out4 and set its frequency
M106 P0 S0 H-1					; set fan 0 value. Thermostatic control is turned off

; Heatbreak Cooling
M950 F1 C"25.out2"				; create fan 1 on pin 25.out2 and set its frequency
M106 P1 H1 T80					; set fan 1 value. Thermostatic control is coupled with nozzle temperature

; Duet Board Cooling
M950 F3 C"out3" Q20000			; create fan 3 on pin out3 and set its frequency
M106 P3 H1 T80					; set fan 3 value. Thermostatic control is coupled with nozzle temperature, active printing implies controller board heat

; Define extruder
M563 P0 D0 H1 F0				; define tool 0
G10 P0 X0 Y0 Z0					; set tool 0 axis offsets
G10 P0 R0 S0					; set initial tool 0 active and standby temperatures to 0C

; enable 12864 LCD, configure LEDs
M918 P2 E4 F2000000
m150 x4 r255 u255 b255 p255

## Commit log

2023-10-21 add E3D Hemera XS + Duet CAN Toolboard + magnetic Z probe extruder
2023-10-29 add bed/z
    [mod0-bed-base-stainless-steel-0.048in-v1.dxf, mod0-bed-no-pockets-180mm-6061-0.25in-v1.dxf, mod0-bed-support-g30-galvanized-0.048in-v1.dxf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]
2023-11-12 initial RRF 3.4.6 configuration
    [config.g, homeall.g, homex.g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]
2023-11-22 Update README.md
    added source for compression springs
2023-11-26 xy-175 v2
    support for nema14/17 steppers
    updated front/rear idler (printed parts)
    changed length of y-extrusion
2023-11-27 add 300mm z configuration
2023-11-27 add z-leadscrew with base
2023-11-30 add prusaslicer config used to print itself
2024-01-28 additional extruder support
    add E3D Hemera XS + EBB 36/FLY RRF 36 CAN Toolboard, E3D Roto + Duet Roto CAN Toolboard
2024-03-02 klipper prusaslicer config
    rename existing slicer configurations, minor adjustments
2024-03-02 separate ebb36/fly36 to better support microfit cable
2024-03-02 initial klipper firmware import
    printer.cfg tuned to mod0 from: https://github.com/makerbase-mks/MKS-SKIPR/blob/main/klipper%20firmware/skipr%20to%20voron%20V2.4.cfg
    the rest from disk image, included as they are linked in printer.cfg: https://drive.google.com/drive/folders/1tTuSvF9OL2qtPXElau8YOXn2sWbdxa9e?usp=sharing
    [fluidd.cfg, mainsail.cfg, moonraker_obico_macros.cfg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]
2024-03-03 z axis update
2024-04-18 update klipper configuration, ldo smart orbiter v3 in comments
    [printer.cfg]
2024-06-06 add mod0-xy-180-v3 (RMRRF/SMF2024 build)
    [mod0-xy-plate-v1.dxf]
2024-07-13 remove LED flicker from bed heater
    [printer.cfg]
2024-08-01 conservative PLA profile for klipper
2024-09-11 prep can-rails folder
2024-09-11 add mod0-xy-180-can-rails-v1
